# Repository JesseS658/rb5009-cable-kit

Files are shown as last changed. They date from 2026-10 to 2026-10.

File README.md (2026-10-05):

# RB5009 Cable Kit

Cable management for a MikroTik RB5009UG+S+ printed on a QIDI MAX 4 in ELEGOO PLA.

**Illustrated guide (PDF):** [RB5009_Cable_Kit.pdf](RB5009_Cable_Kit.pdf)
Click any file in `stl/` to see it in 3D; use the download button (↓ "Download raw file") to save it.
Every part prints in the orientation it is saved in, without supports.

Times and weights are OrcaSlicer 2.4.2 estimates (0.20 mm Standard @ X-Max 4, Textured PEI, PLA 220 °C / 55 °C).

| Code | Part | File | Size, mm | Print time | Filament |
|---|---|---|---|---|---|
| A | Router dock | `stl/A1_rb5009_dock.stl` | 254 × 300 × 37 | 6 h 51 min | 228 g |
| A | Dock lock bar (flip onto the comb) | `stl/A2_dock_lock_bar.stl` | 230 × 11 × 10 | 25 min | 8 g |
| B | Port comb | `stl/B1_port_comb.stl` | 240 × 51 × 38 | 2 h 07 min | 56 g |
| B | Comb lock bar | `stl/B2_port_comb_lock_bar.stl` | 240 × 11 × 10 | 26 min | 8 g |
| C | Raceway base, 300 mm | `stl/C1_raceway_base.stl` | 300 × 57 × 24 | 1 h 56 min | 80 g |
| C | Raceway base with side exits | `stl/C2_raceway_base_exits.stl` | 300 × 57 × 24 | 1 h 57 min | 78 g |
| C | Raceway lid (prints upside down) | `stl/C3_raceway_lid.stl` | 300 × 60 × 10.5 | 1 h 07 min | 47 g |
| C | Raceway joiner | `stl/C4_raceway_joiner.stl` | 40 × 29 × 10 | 17 min | 3 g |
| D | Under-desk basket | `stl/D1_underdesk_basket.stl` | 330 × 170 × 80 | 8 h 27 min | 237 g |
| E | 12 cable tags (1–8, F, U, P, P) | `stl/E1_cable_tags.stl` | 129 × 45 × 9 | 30 min | 8 g |
| E | 6 stick-on holders | `stl/E2_adhesive_holders.stl` | 91 × 60 × 16 | 1 h 05 min | 23 g |
| F | Fit-test plate (print first) | `stl/F1_fit_test.stl` | 160 × 60 × 37 | 1 h 14 min | 29 g |

Comb slot labels: P = DC power, F = SFP+, U = USB, 1–8 = Ethernet ports.
Port positions are estimated (standard 15.88 mm jack pitch); print F first and hold it against ports 1–3.

`source/make_designs.py` regenerates every part (Python, manifold3d + trimesh).

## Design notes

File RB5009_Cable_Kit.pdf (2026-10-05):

## CABLE MANAGEMENT FOR MIKROTIK RB5009UG+S+ · QIDI MAX 4 · ELEGOO PLA

# RB5009 Cable Kit

Six 3D-printable designs built around your router: a 220 × 125 mm RB5009 with

eight Ethernet ports, an SFP+ cage, USB and a 24 V DC jack on the front. Every part has been sliced in OrcaSlicer with your printer's profile and passed the safety

check, so the times and weights are real estimates.

0 mm | 220 mm

RST

P | F | U | 1 | 2 | 3 | 4 | 5 | 6 | 7 | 8

Router front panel to scale. Every comb has one slot per connector with the same label: P = DC power, F = SFP+, U = USB, 1–8 = Ethernet ports.

# A Router Dock

## 7 h 16 min · 236 g

# B Port Comb

## 2 h 33 min · 64 g

# C Twin-Lane Raceway

## 3 h 03 min per 300 mm · 127 g

# D Under-Desk Basket

## 8 h 27 min · 237 g

# E Tags and Holders

## 1 h 35 min · 32 g

# F Fit Test

## 1 h 14 min · 29 g

# Start with F

The fit-test plate takes 1¼ hours.

Check the comb slots against your ports and feel the raceway lid click,

before a long print.

# Best single print: A

The dock organises everything

around the router. Overnight, about

7¼ hours.

# Filament

One 1 kg roll, about 985 g left. F + A

+ E use about 300 g. Everything here, one of each: about 805 g.

# A Router Dock

### RECOMMENDED

A base plate the router sits in, with everything around it organised: a numbered comb in front of the ports, a separate lane for the DC cord and a vented bay at the back for the power brick.

## Dock with the router in place (blue outline)

Dock without the router | From the back: brick bay | A2 lock bar (pins up)

# What it does

Router sits on rails with a 3.5 mm air gap, held by four

corner posts, and lifts straight out.

Comb 45 mm in front of the ports, one slot per connector, labelled P F U 1–8. The lock bar closes the slots.

DC cord runs from the brick bay along the left lane under three cable bridges to the jack.

Brick bay: open top, vented walls, three strap loops, cord exits to the lane and out the back.

Four strap loops in front of the comb to bundle the cables as they leave.

# How to use it

1. Print A1 overnight, then A2 (25 min).

### 2. Put the dock where the router lives and set the router

between the four corner posts, ports facing the comb.

### 3. Plug in each cable and lay it in the slot with the same

number. Lay the power cord in slot P.

### 4. Press the lock bar onto the top of the comb: its pins go into

the holes between the slots.

### 5. Put the power brick in the back bay and hold it with a velcro

strap through the loops. Run the DC cord out of the bay's

left opening, forward along the left lane under the three

bridges, to the jack.

### 6. Bundle the cables in front of the comb with velcro straps

through the front loops.

PART | SIZE, MM | PRINT TIME | FILAMENT
A1 dock | 254 × 300 × 37 | 6 h 51 min | 228.3 g
A2 lock bar | 230 × 11 × 10 | 25 min | 7.8 g
Total | | 7 h 16 min | 236.1 g

# B Port Comb

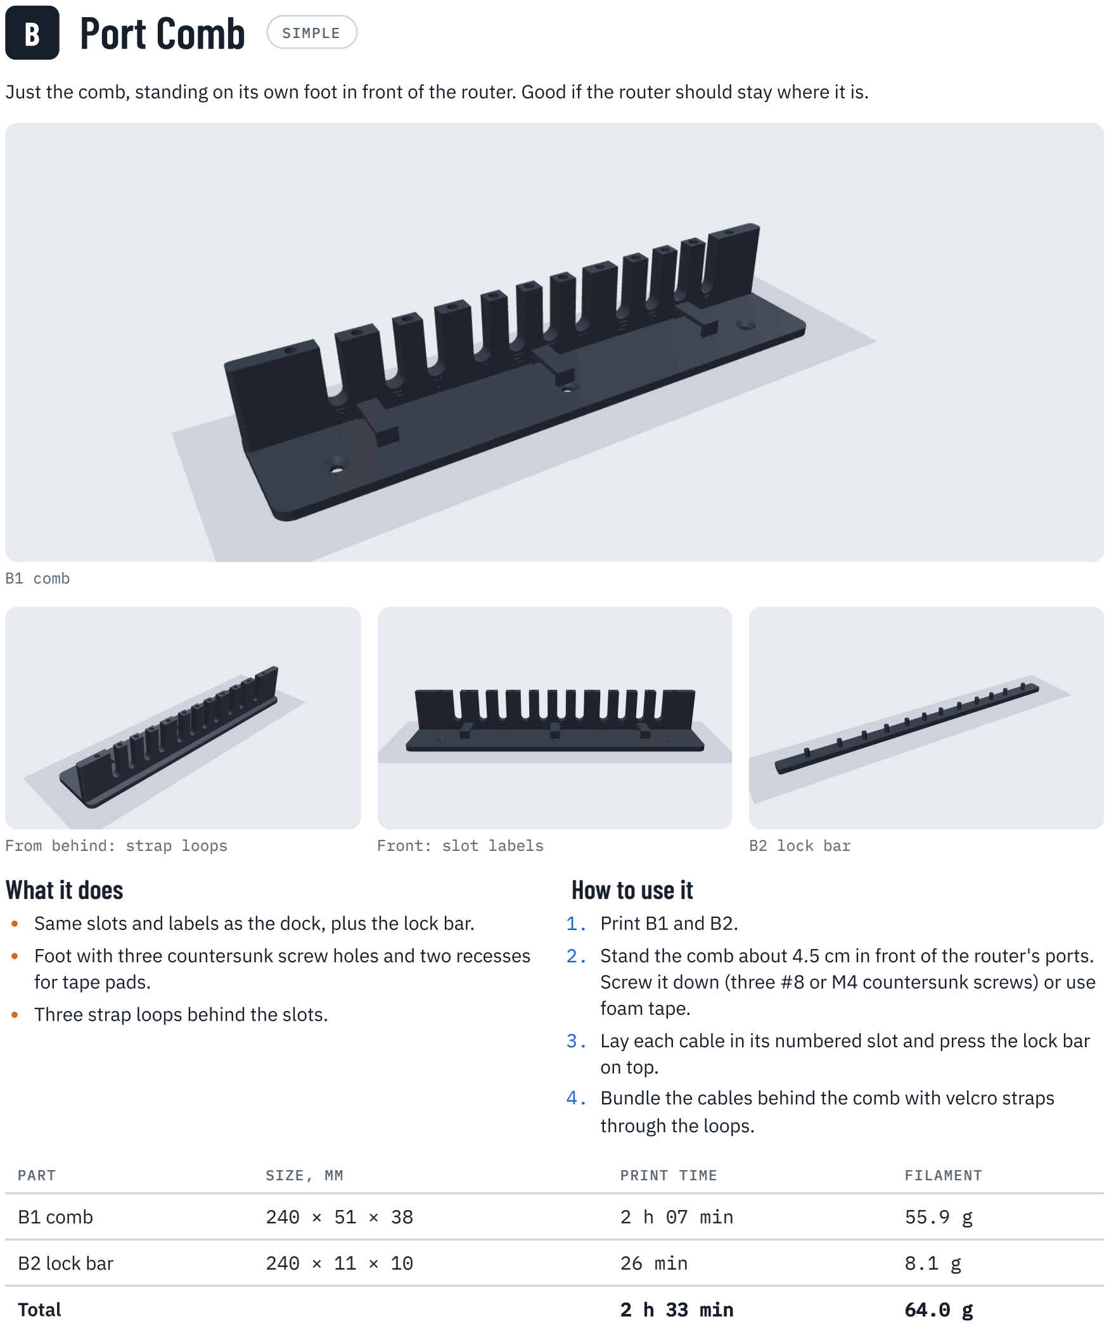
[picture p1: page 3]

### SIMPLE

Just the comb, standing on its own foot in front of the router. Good if the router should stay where it is.

## B1 comb

From behind: strap loops | Front: slot labels | B2 lock bar

# What it does

Same slots and labels as the dock, plus the lock bar.

Foot with three countersunk screw holes and two recesses for tape pads.

Three strap loops behind the slots.

# How to use it

1. Print B1 and B2.
2. Stand the comb about 4.5 cm in front of the router's ports.

Screw it down (three #8 or M4 countersunk screws) or use foam tape.

### 3. Lay each cable in its numbered slot and press the lock bar

on top.

### 4. Bundle the cables behind the comb with velcro straps

through the loops.

PART | SIZE, MM | PRINT TIME | FILAMENT
B1 comb | 240 × 51 × 38 | 2 h 07 min | 55.9 g
B2 lock bar | 240 × 11 × 10 | 26 min | 8.1 g
Total | | 2 h 33 min | 64.0 g

# C Twin-Lane Raceway

### MODULAR

A covered channel for cable runs along a wall, desk edge or skirting board. The data lane and the power lane are separated by a

wall, and the lid clicks on.

## C1 base

C2 base with side exits | C3 lid (printed upside down) | C4 joiner

# What it does

LAN lane 30 mm wide (about 10–12 Cat6 cables); power lane 19.6 mm (two cords).

Segments are 300 mm. Fit lids offset from the bases so every seam is covered; the joiner clip lines up two bases.

C2 has two side exits for cables that leave part way along.

Countersunk screw holes in both lanes, or mounting tape

on the flat back.

# How to use it

### 1. Plan the run and count 30 cm pieces. Use C2 where cables

leave part way along.

### 2. Screw or tape the bases end to end. A C4 joiner in the LAN

lane lines up each seam.

### 3. Lay network cables in the wide LAN lane and power cords

in the narrow lane.

### 4. Click the lids on, shifted half a piece from the bases so

every seam is covered. Pry a lid off at its finger notch.

PART | SIZE, MM | PRINT TIME | FILAMENT
C1 base | 300 × 57 × 24 | 1 h 56 min | 79.6 g
C2 base, side exits | 300 × 57 × 24 | 1 h 57 min | 78.3 g
C3 lid | 300 × 60 × 10.5 | 1 h 07 min | 46.9 g
C4 joiner | 40 × 29 × 10 | 17 min | 3.3 g
Total (base + lid) | | 3 h 03 min per 300 mm | 126.5 g

# D Under-Desk Basket

### OVERNIGHT

A vented tray that screws under the desk and holds the power strip, the router's power brick and the extra cable length, so

nothing lies on the floor.

## D1 basket

From the back: cord notches | From above: vented floor | Screw brackets

# What it does

Inside 325 × 125 × 77 mm, fits most 6-outlet power strips.

Six screw points on solid 45° brackets (no supports needed); heads sit in recesses under the flange.

Cord notches in the back wall and both ends; three strap

loops on the floor for the strip.

Vented floor and walls for the brick's heat.

# How to use it

### 1. Choose a spot under the desk and hold the basket up to

mark the six holes.

### 2. Use screws at least 3 mm shorter than the desk is thick (for

an 18 mm desk, 15 mm screws). Drill small pilot holes first.

### 3. Put the power strip and brick inside and strap the strip

down through the floor loops.

### 4. Run the cords out through the notches in the back wall and

the ends.

PART | SIZE, MM | PRINT TIME | FILAMENT
D1 basket | 330 × 170 × 80 | 8 h 27 min | 236.6 g

# E Tags and Holders

### QUICK

Small helpers: numbered tags that clip onto each cable so you know which port it goes to, and stick-on holders for the far end of a

run.

## E1 tags

Tags from above | E2 stick-on holders | Holder channels

# What it does

Twelve tags: 1–8, F, U and two P. They clip onto 5.5–6.5

mm cables with the number facing out.

Six holders: three with four 6 mm channels for network cables and three with two 8 mm channels for power cords.

Stick them on with double-sided tape.

# How to use it

### 1. Clip a tag onto each cable near both ends, number facing

out.

### 2. Stick holders on with double-sided tape on a clean, dry

surface; press for 30 seconds.

### 3. Use the 6 mm holders for network cables and the 8 mm

holders for power cords.

PART | SIZE, MM | PRINT TIME | FILAMENT
E1 tags | 129 × 45 × 9 | 30 min | 8.3 g
E2 holders | 91 × 60 × 16 | 1 h 05 min | 23.3 g
Total | | 1 h 35 min | 31.5 g

# F Fit Test

### PRINT FIRST

One small plate with a sample of each tricky fit. Print it before a long job and check it against the real router and cables.

## F1 test plate

From behind | From above | Front: slots 1–3

# What it does

Three comb slots at the spacing of ports 1–3, with a short

lock bar.

A 40 mm raceway base and lid, to feel the snap.

One cable tag, to try on your thickest cable.

# How to use it

1. Print it (about 1¼ hours).
2. Hold the comb section about 4.5 cm in front of ports 1–3.

The cables should run straight into slots 1, 2 and 3.

### 3. Press the small lock bar on, then the raceway lid on and off

a few times: it should click and stay.
4. Clip the tag onto your thickest cable.

### 5. Tell Claude what you found. If the slots are off, the designs

get adjusted before the long prints.

PART | SIZE, MM | PRINT TIME | FILAMENT
F1 test plate | 160 × 60 × 37 | 1 h 14 min | 29.0 g

## CHECKED IN THE DESIGN

# Edge cases

SITUATION | HOW THE KIT HANDLES IT
Port positions | MikroTik publishes no port drawing, so slot positions come from the standard 15.88 mm jack pitch and product photos. Slots are 7.6 mm wide and sit 45 mm in front of the ports, so a few millimetres of error only angles a cable slightly. Plate F tests three slots against ports 1–3 first.
Different cable sizes | Slots take Cat5e (5 mm) through Cat6 (6–6.5 mm), flat cables on edge, DAC and USB cables. Tags clip onto 5.5–6.5 mm cables. Holders come in 6 mm and 8 mm.
Adding or removing a cable later | Every slot, lane and holder opens from the top, so no plug has to pass through a hole. Lift the lock bar or lid, drop the cable in and close it.
Router heat | The RB5009 cools through its case. The dock touches it only on thin rails and corner posts, leaves a 3.5 mm air gap with vent windows underneath, and keeps the top and fins open. PLA softens around 55–60 °C; if the case gets too hot to hold comfortably, reprint the dock in PETG.
Power brick heat | The brick bay and the basket have open tops and vented walls, and nothing wraps the brick tightly.
Power next to data | The DC cord has its own lane in the dock, the raceway has a walled power lane, and the mains cord leaves the brick bay at the back.
Buttons, lights and the side terminal | Reset button, LEDs, USB and SFP+ stay reachable. The corner posts are 16 mm long, so the 2-pin power terminal and ground screw on the left end stay uncovered. The router lifts out without tools.
Cable bending | Cables run straight from the port to the comb (Cat6 wants a bend radius of 25 mm or more; fiber 30 mm). Strap loops sit after the comb, not at the port.
Screws | Countersunk holes for #8 or M4 wood screws, or tape on any flat back. The basket screws up into the desk with the heads recessed. Use screws at least 3 mm shorter than the desk is thick.
Printing | Every part prints flat, needs no supports and fits the 390 mm bed. The raceway lid prints upside down; lock-bar pins print pointing up.
Snap fits | The raceway lid flexes about 0.6 mm to click on (about 2 % strain, safe for PLA) and has a finger notch to pry it off. Lock-bar pins have a slit so they press in without cracking the comb.

# Printing a part

1. Tell Claude which letters you want, for example "F, then A overnight", and any changes.
2. Claude slices it with the locked profile, runs the safety check and uploads it, then the print starts only after you confirm at the

printer.

3. A monitor watches temperatures and progress during the print and stops it on a fault.

Files: https://github.com/JesseS658/rb5009-cable-kit · Generated 2026-10-05 · OrcaSlicer 2.4.2 · 0.20 mm Standard @ X-

Max 4 · Textured PEI · ELEGOO PLA 220 °C / 55 °C

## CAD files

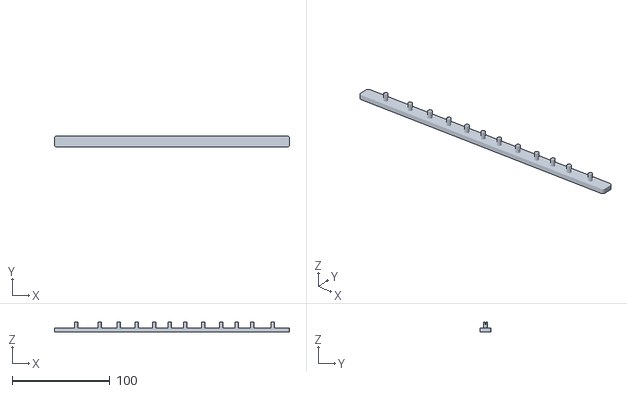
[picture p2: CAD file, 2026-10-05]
stl/B2_port_comb_lock_bar.stl
240.0 x 11.0 x 9.99

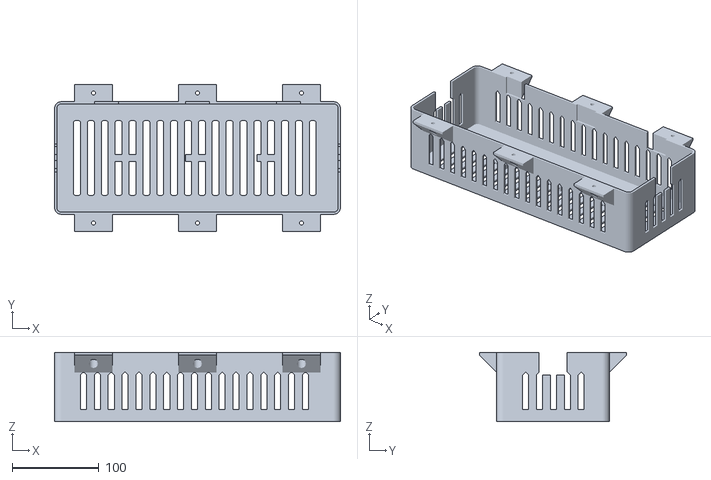
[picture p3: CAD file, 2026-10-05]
stl/D1_underdesk_basket.stl
330.0 x 170.0 x 80.0

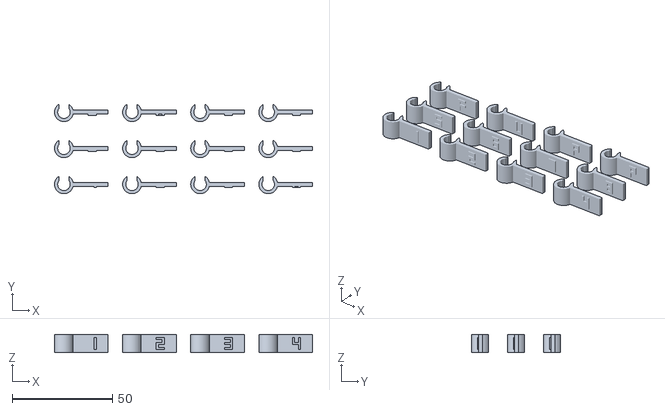
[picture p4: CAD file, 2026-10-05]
stl/E1_cable_tags.stl
128.8 x 44.7 x 9.00

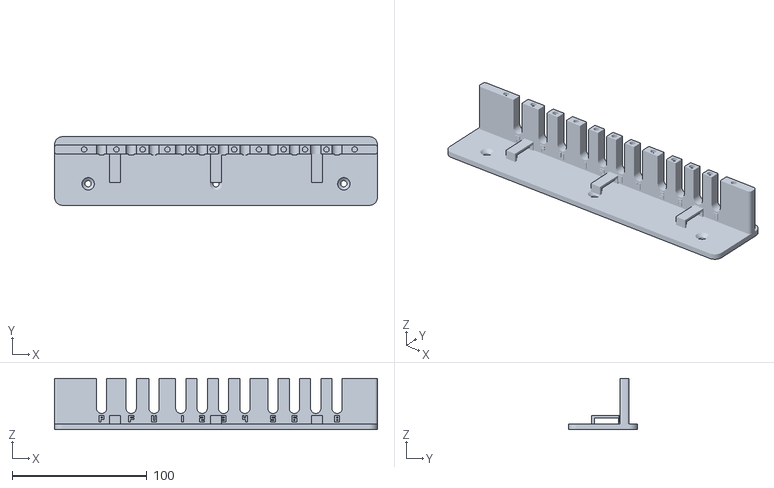
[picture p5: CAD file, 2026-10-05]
stl/B1_port_comb.stl
240.0 x 51.0 x 38.0

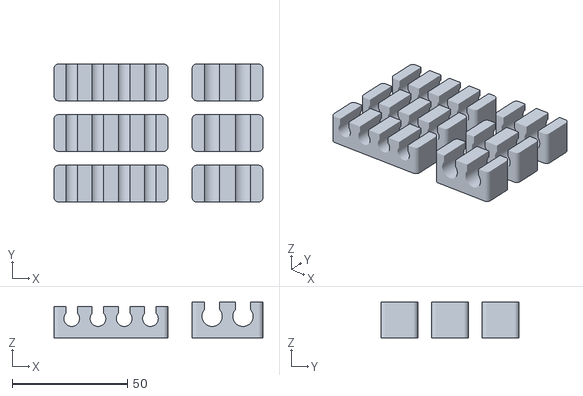
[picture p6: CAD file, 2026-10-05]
stl/E2_adhesive_holders.stl
90.8 x 60.0 x 15.6

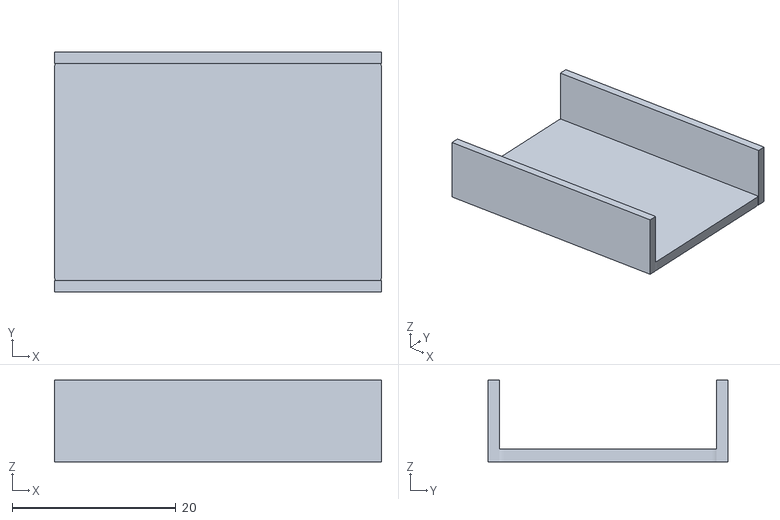
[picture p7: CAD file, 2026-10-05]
stl/C4_raceway_joiner.stl
40.0 x 29.4 x 10.0

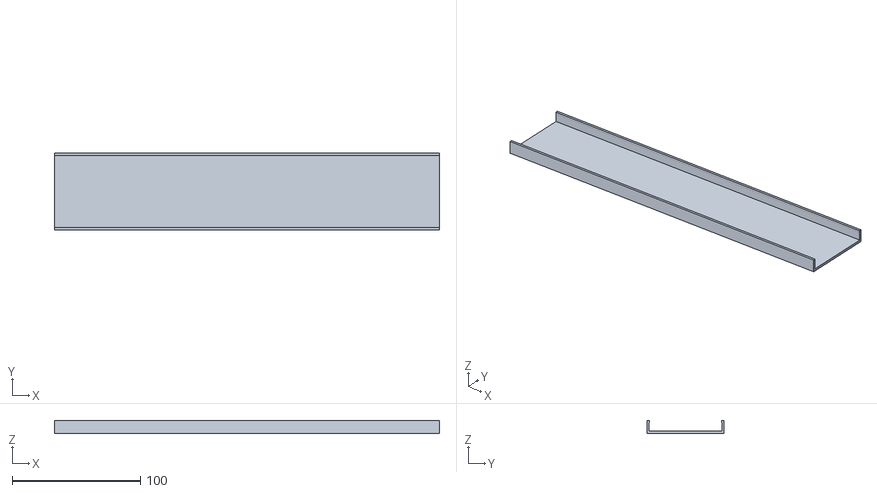
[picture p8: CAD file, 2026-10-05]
stl/C3_raceway_lid.stl
300.0 x 59.8 x 10.5

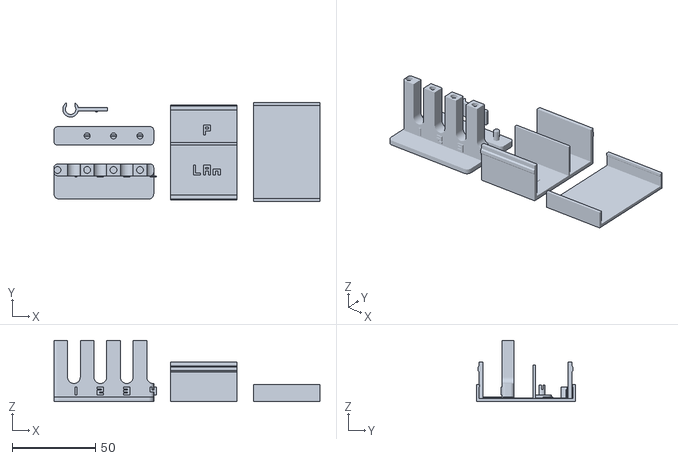
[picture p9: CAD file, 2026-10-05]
stl/F1_fit_test.stl
160.0 x 59.8 x 37.0

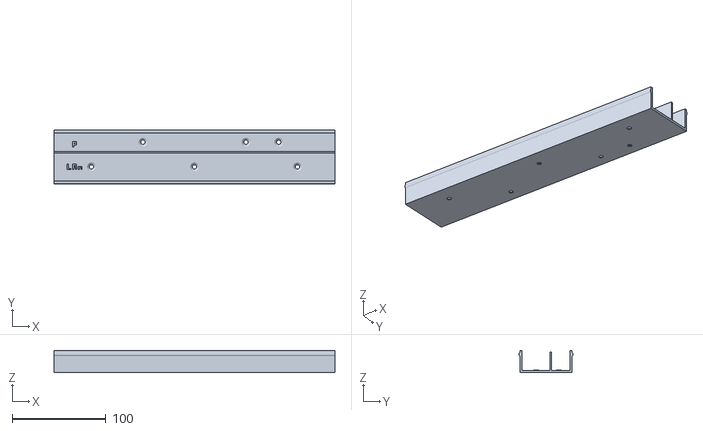
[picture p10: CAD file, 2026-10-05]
stl/C1_raceway_base.stl
300.0 x 57.2 x 24.0

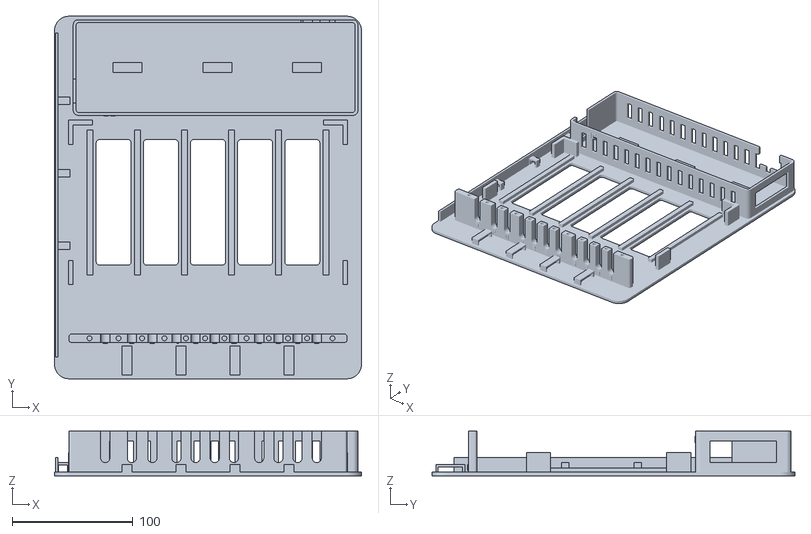
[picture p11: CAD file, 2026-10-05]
stl/A1_rb5009_dock.stl
254.0 x 300.0 x 37.0

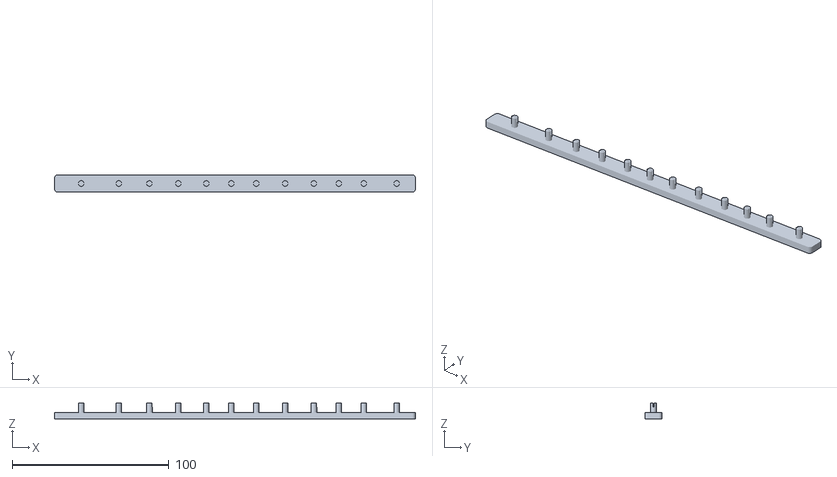
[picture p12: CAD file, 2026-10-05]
stl/A2_dock_lock_bar.stl
230.0 x 11.0 x 9.99

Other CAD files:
stl/C2_raceway_base_exits.stl
